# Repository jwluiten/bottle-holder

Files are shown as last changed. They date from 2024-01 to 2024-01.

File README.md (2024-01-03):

# Ultimate Bottle Holder

I have this long 3DLack spray can, that I wanted to mount on my honeycomb panel. I tried to find a side-mounted bottle holder to waste as little space on my HC panel as possible. I found a few, but none had the correct inner diameter.
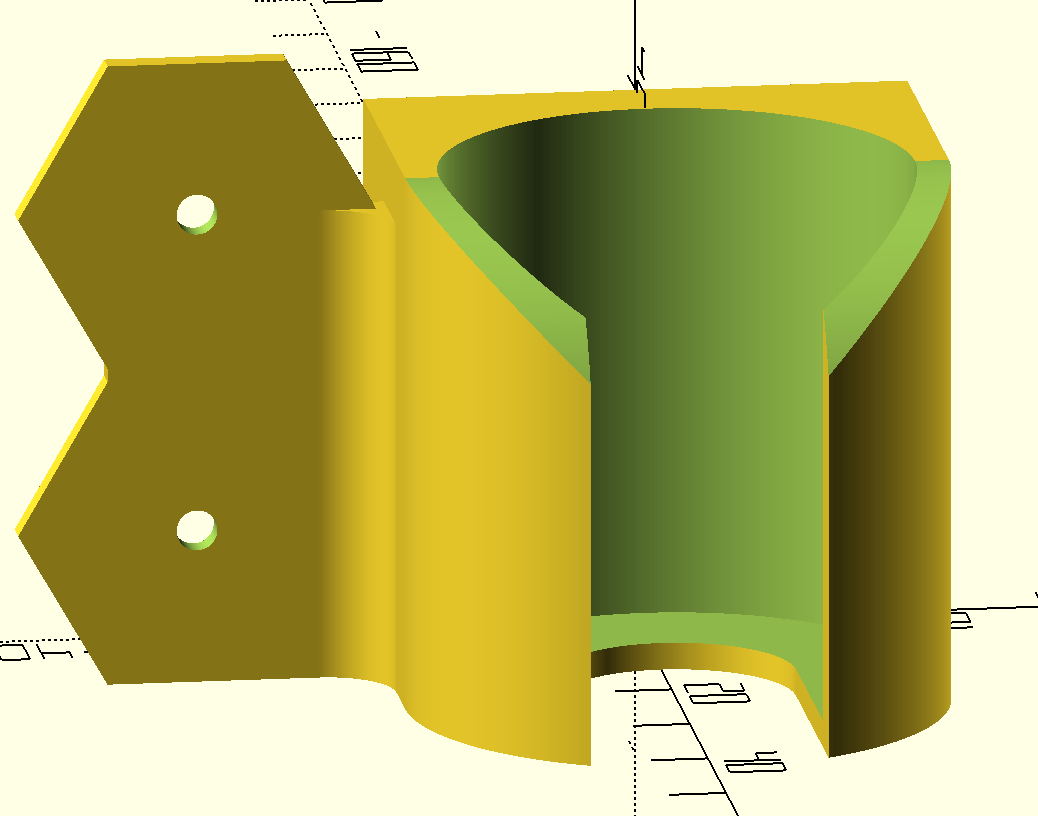
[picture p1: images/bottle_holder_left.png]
bottle holder left

Using OpenSCAD I designed a customizable bottle holder. I can now print bottle holders with any diameter and any height that connect to either the left or the right side of my HC panel

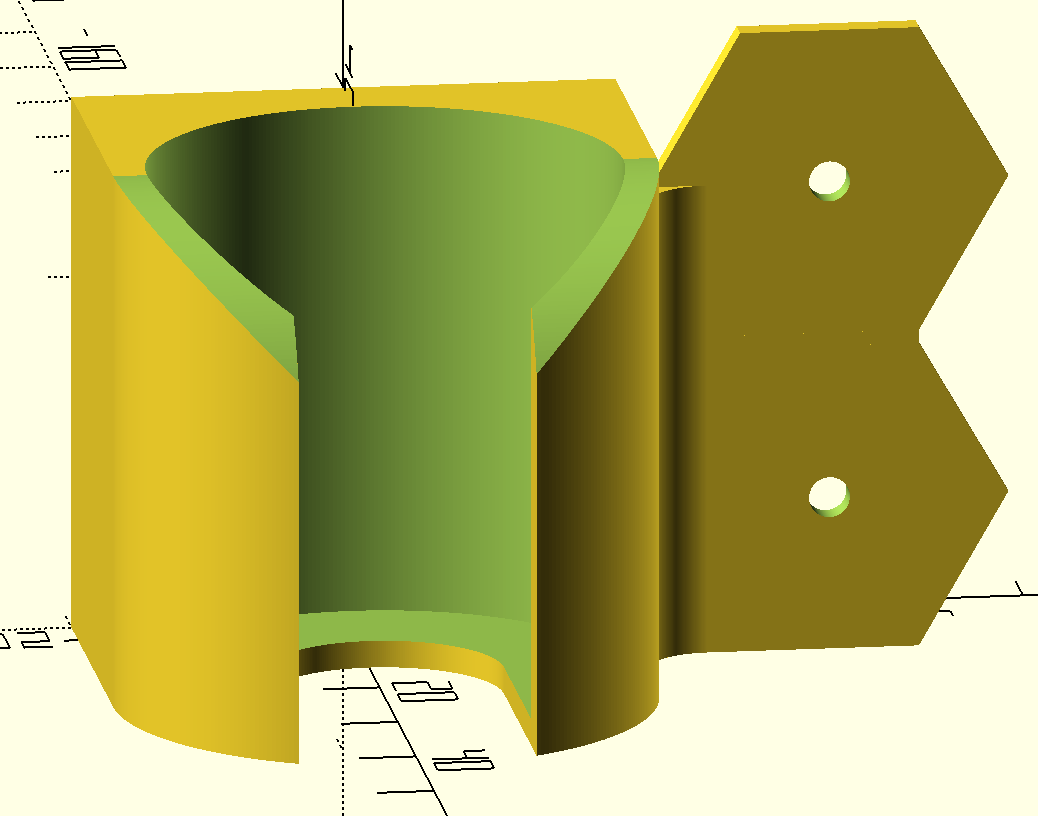
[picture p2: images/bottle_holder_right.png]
bottle holder right


Smaller bottles don't take that much space and can be mounted on the panel directly.

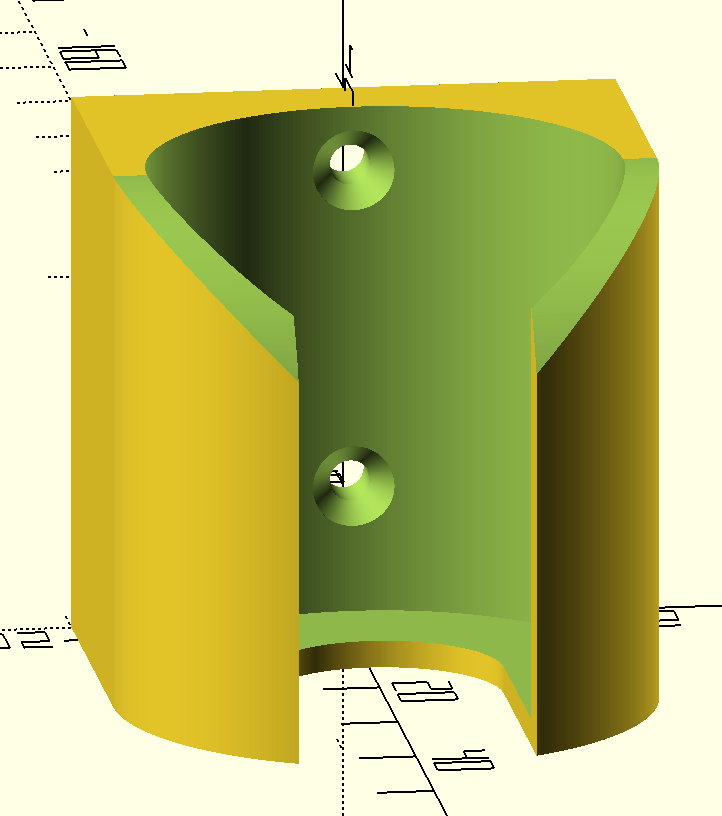
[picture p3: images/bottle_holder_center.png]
bottle holder center


The holder is connected to the HC panel using the [connectors](https://www.printables.com/model/511970-honeycomb-wall-system-openscad-connectors) designed by [James Gilliland](https://www.printables.com/@neclimdul).
I added STL files for M3, M4 and M5 connectors.

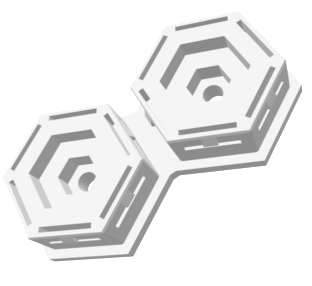
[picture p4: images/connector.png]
James Gilliland connector


## Customizable features
Below image show the customizable features of the bottle holder
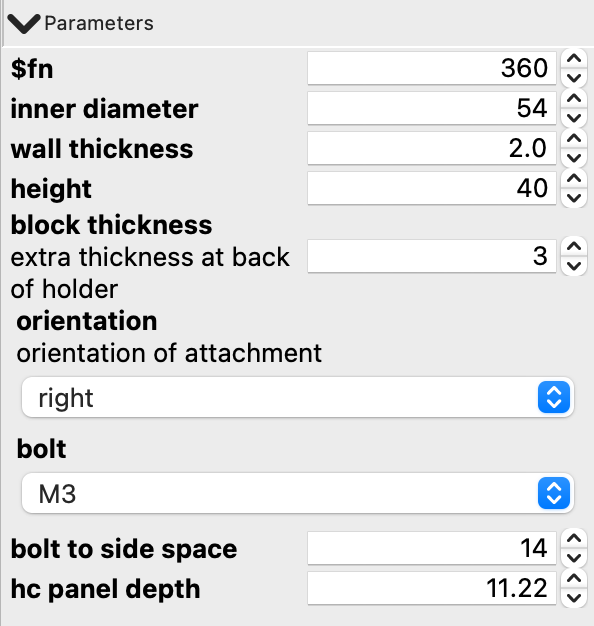
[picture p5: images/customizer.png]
customizer


### inner diameter
For the 3DLack bottle I used 55 as inner diameter.

### height
For small bottles I used 40. For the large 3DLack bottle I used 60.

### wall thickness
For wall thickness I used 2.0.

### block thickness
At the wall side of the holder, a block is appended. This parameter sets the thickness of that block. The total thickness at the wall side of the holder thus is `wall thickness + block thickness`.

### orientation
- `left` draws the attachement on the left side
- `right` draws the attachment on the right side
- `center` does not draw an attachment but provides countersunk holes in the back of the holder. For a height < 40, it draws a single hole. For height >= 40 it draws two countersunk holes.
- `none` only draws the bottle holder. No countersunk holes no attachment.

### bolt
I used M3. The model has options for M2.5, M3, M4 and M5.
3DLack holder

### bolt to side space
This is the distance between the center of the bolt holes on the clip and the side of the panel. For my panels, which do not have a border, this distance is 14 mm. Make sure to correctly measure this value before printing the model.
X-MAX 3 printing

### hc panel depth
This sets the distance between the back of the holder and the left or right attachment. For my panel this is a little more than 11mm.

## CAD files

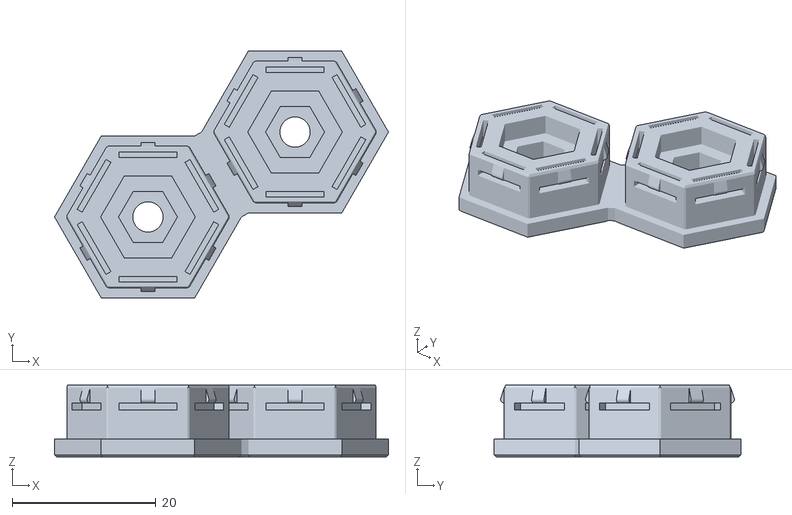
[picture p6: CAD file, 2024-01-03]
connectors/two-m4.stl
46.4 x 34.3 x 10.0

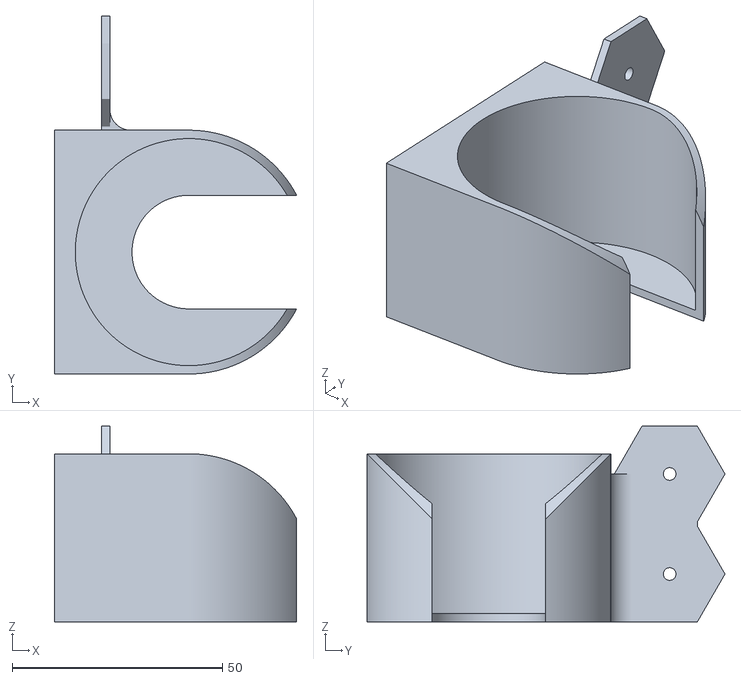
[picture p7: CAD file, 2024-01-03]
holders/holder-right-54mm.stl
57.7 x 85.2 x 46.6

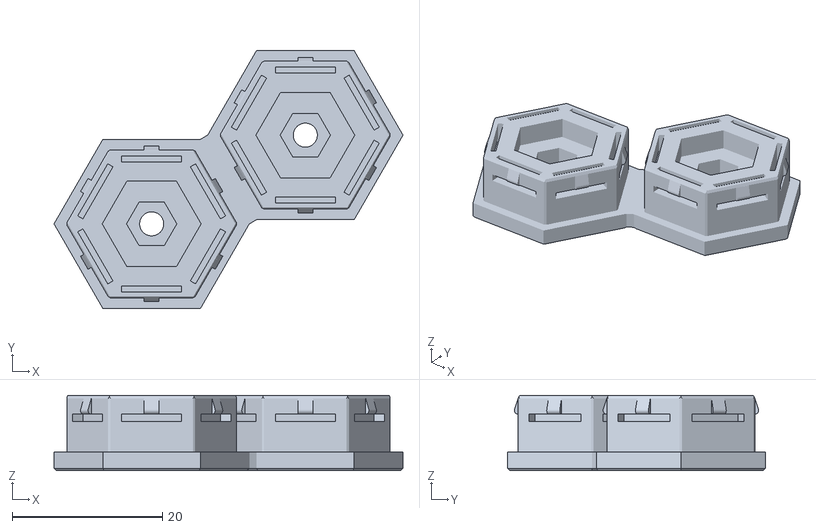
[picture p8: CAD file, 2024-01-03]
connectors/two-m3.stl
46.4 x 34.3 x 10.0

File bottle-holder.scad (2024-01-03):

include <BOSL2/std.scad>
bolts = import("bolts.json");

$fn = 360;

inner_diameter = 55; //[::non-negative float]

wall_thickness = 2.5; //[::non-negative float]

height = 60; //[::non-negative integer]

// extra thickness at back of holder
block_thickness = 3; //[::non-negative integer]

// orientation of attachment
orientation = "right"; // [left,right, center, none]

bolt = "M3"; //[M2.5,M3,M4,M5]
bolt_to_side_space = 14;

hc_panel_depth = 11.22;
/* [Hidden] */

// stuff for honeycomb hexagons
hexa_radius = 11.4;
hexa_circular_radius = hex_to_circular_radius(hexa_radius);
hexa_side_length = sqrt((hexa_circular_radius * hexa_circular_radius - hexa_radius * hexa_radius) / 0.25);

// stuff for the holder
inner_radius = inner_diameter / 2;
outer_radius = inner_radius + wall_thickness;
outer_diameter = outer_radius * 2;
holder_depth = block_thickness + outer_diameter;
mask_height = min(height, 3 * hexa_radius + 1);


bottle_holder_and_attachment();

module bottle_holder_and_attachment()
{
    difference()
    {
        union()
        {
            bottle_holder();
            if (orientation == "right")
            {
                translate([ hc_panel_depth, outer_radius, 0 ]) attachment();
                translate([ hc_panel_depth + 2, outer_radius, 0 ])
                    rounding_edge_mask(l = mask_height, r = 5, orient = UP, anchor = BOTTOM);
            }
            else if (orientation == "left")
            {
                rotate([ 0, 0, 180 ]) translate([ -13.22, outer_radius, 0 ]) attachment();
                translate([ 13.22, -outer_radius, 0 ])
                    rounding_edge_mask(l = mask_height, r = 5, orient = UP, anchor = BOTTOM, spin = 270);
            }
        }
        if (orientation == "center")
        {
            head_radius = bolts[bolt].countersunk.head_diameter / 2;
            if (height >= (hexa_radius + head_radius + 2))
            {
                translate([ block_thickness + wall_thickness, 0, hexa_radius ]) rotate([ 0, 90, 0 ]) _bolt(bolt);
            }
            if (height >= (3 * hexa_radius + head_radius + 2))
            {
                translate([ block_thickness + wall_thickness, 0, 3 * hexa_radius + 1 ]) rotate([ 0, 90, 0 ])
                    _bolt(bolt);
            }
        }
    }
}

module attachment()
{
    rotate([ 0, 90, 0 ]) translate([ -3 * hexa_radius - 1, bolt_to_side_space, 0 ]) union()
    {
        _single_hex_prism();
        translate([ hexa_radius, -hexa_side_length / 2, 0 ]) cube(size = [ 1, hexa_side_length, 2 ]);
        translate([ 2 * hexa_radius + 1, 0, 0 ]) _single_hex_prism();
        translate([ 0, -bolt_to_side_space, 0 ])
            cube(size = [ 3 * hexa_radius + 1, bolt_to_side_space - hexa_side_length / 2, 2 ]);
    }
}

module _bolt(bolt_name)
{
    data = bolts[bolt_name].countersunk;
    head_length = data.head_length;
    head_diameter = data.head_diameter;
    pin_length = block_thickness + wall_thickness;
    total_length = 2 * head_length + pin_length;

    translate([ 0, 0, -(pin_length + head_length) ]) union()
    {
        cylinder(h = pin_length, d = data.diameter, center = false);
        translate(v = [ 0, 0, pin_length ]) cylinder(h = head_length, d1 = diameter, d2 = head_diameter);
        translate(v = [ 0, 0, pin_length + head_length ]) cylinder(h = head_length, d = head_diameter);
    }
}

module _single_hex_prism()
{
    rotate([ 0, 0, 30 ]) difference()
    {
        cylinder(h = 2, r = hexa_circular_radius, $fn = 6);
        translate([ 0, 0, -0.01 ]) cylinder(h = 2.02, d = bolt_diameter(bolt));
    }
}


module bottle_holder()
{
    difference()
    {

        bottle3D();
        // subtract inner cylinder
        translate([ block_thickness + outer_radius, 0, 2 ]) cylinder(h = height, d = inner_diameter);
        // subtract rounding
        translate([ holder_depth, 0, height ]) rotate([ 90, 180, 0 ])
            rounding_edge_mask(l = inner_diameter + wall_thickness * 2, r = outer_radius);
    }
}

module bottle3D()
{
    linear_extrude(height) _bottle2d();
}

module _bottle2d()
{
    block_y = outer_radius * 2;
    block_x = block_thickness + outer_radius; // also x-coord of center point of circles
    union()
    {
        difference()
        {
            union()
            {
                // wall block
                translate([ 0, -outer_radius, 0 ]) square([ block_x, block_y ]);
                //  add outer circle
                translate([ block_x, 0, 0 ]) circle(outer_radius);
            }
            // subtract inner block
            translate([ block_x, 0, 0 ]) circle(inner_radius / 2);
            translate([ block_x, -inner_diameter / 4, 0 ]) square([ outer_radius, inner_diameter / 2 ]);
        }
    }
}

function hex_to_circular_radius(d) = d / sqrt(3) * 2;
function bolt_diameter(bolt_name) = bolts[bolt_name].countersunk.diameter;

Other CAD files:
connectors/two-m5.stl
holders/holder-left-54mm.stl
